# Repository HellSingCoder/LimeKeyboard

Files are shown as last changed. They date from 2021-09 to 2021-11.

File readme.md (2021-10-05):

# Lime Keyboard

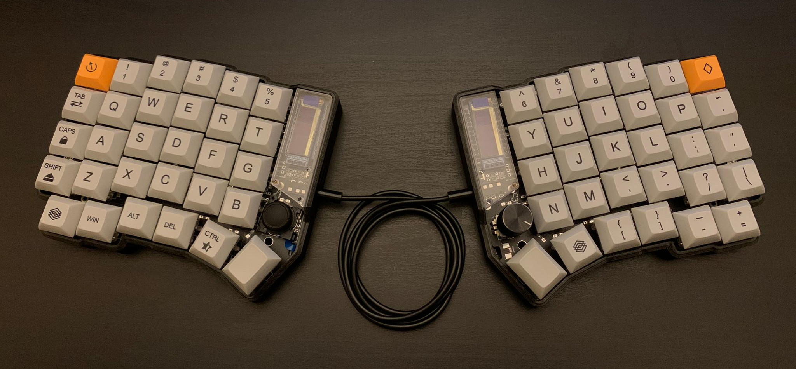
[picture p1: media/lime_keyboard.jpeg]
Lime Keyboard


Lime is a 6×4+6 keys column-staggered split keyboard with encoder and joystick support. Based on [Lily58](https://github.com/kata0510/Lily58), [Corne](https://github.com/foostan/crkbd), [Helix](https://github.com/MakotoKurauchi/helix) and [Sofle](https://github.com/josefadamcik/SofleKeyboard) keyboards. This board features a reversible PCB, OLEDs, Underglow and Bluetooth support. The PCB has holes for floating or screwed mounts but can be also mounted with a gasket.

The Lime keyboard was created by [HellTM](https://github.com/HellSingCoder) with the help of the QMK and custom keyboard community.

**If you would like one of these contact me, I will probably run a couple batches in the future.**

## Firmware 

This keyboard runs [QMK](https://qmk.fm/) (no VIA support).

## Default layout 

### Base layer
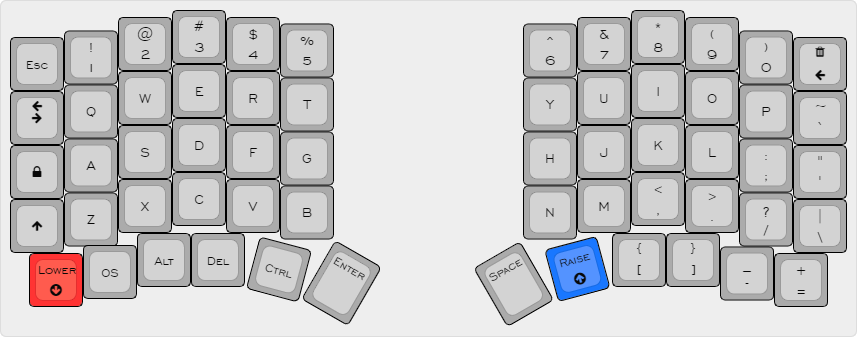
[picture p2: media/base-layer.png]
Base layout for Lime Keyboard

The layout can be switched for COLEMAK in the settings layer

### Lower layer
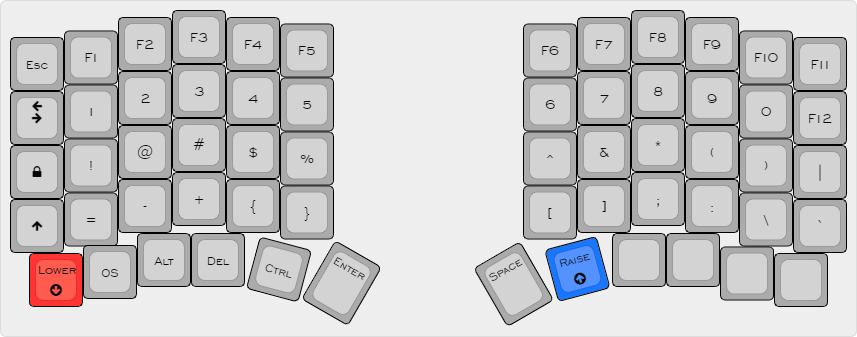
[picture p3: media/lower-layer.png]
Lower layout for Lime Keyboard


### Raise layer
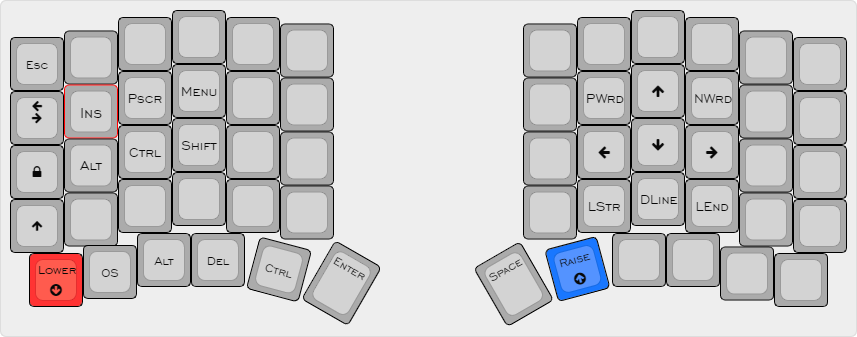
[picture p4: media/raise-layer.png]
Raise layout for Lime Keyboard


### Settings layer
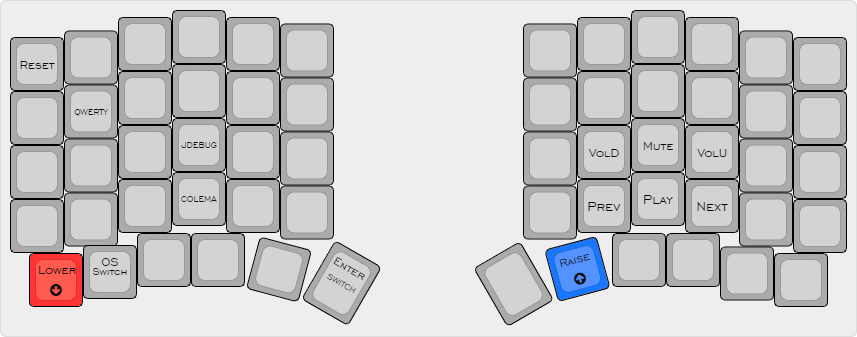
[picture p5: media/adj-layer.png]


This layer can be accessed with the following combination:

Adj layout combination for Lime Keyboard

## Extras

### Keyboard Pet (Luna)
Adj layout for Lime Keyboard

Luna jumps every time you hit Space and will bark at people on the internet if you activate Caps Lock!

This keyboard pet reacts to your WPM counter:
- under 10 -> sit
- between 10 and 50 -> walk
- over 50 -> run

### Shift + Backspace = Delete
This one is pretty self explanatory.

### Space / Enter swap
The Enter and Space functions can be swapped pressing the left thumb button from the Setting layer. The current mode will be displayed on the left display. This one may be useful to all the gamers out there!

### OS Switch
Pressing the OS button while on the settings layer will toggle the MAC / WIN mode. This corrects the behaviour of the Alt and Control modifiers. The current selection will be displayed with an icon at the top of the left display.

### Media Buttons
The right encoder controls the volume and can be pressed to mute. Extra media buttons are hidden away on the settings layer.

### RGB Underglow Support
The board features a 5 LEDs extensible or overridable underglow. Unfortunately, the default keymap does not take advantage of that because of the very limited space but, the option is out there if you want to play around with it.

### WPM indicator
Current WPM will be displayed at the bottom of the right screen.

### Joystick Debug
The JDebug button on the settings layer toggles the ADC readings of the joystick pins for X and Y axis. These will be displayed on the left OLED.

## Special thanks

[Envious](https://github.com/Envious-Data) - Kicad sage

[Dasky](https://github.com/daskygit) - Joystick Troubleshooting guru

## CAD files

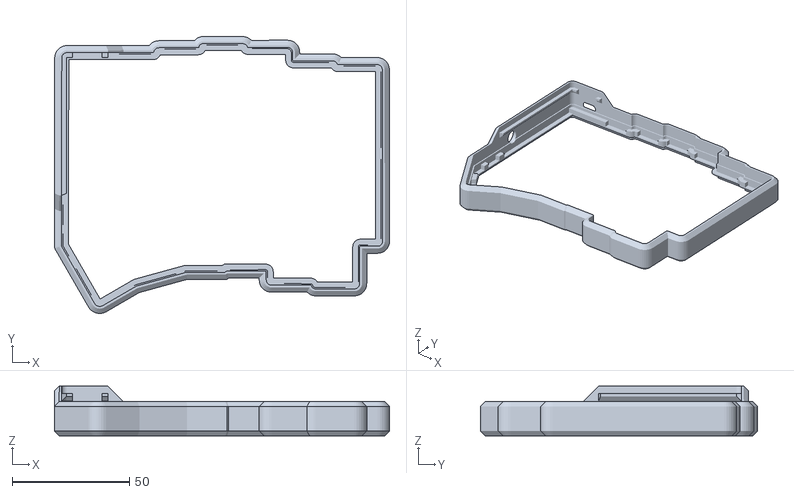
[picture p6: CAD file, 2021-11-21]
case/bumper R.stl
142.6 x 117.9 x 21.1

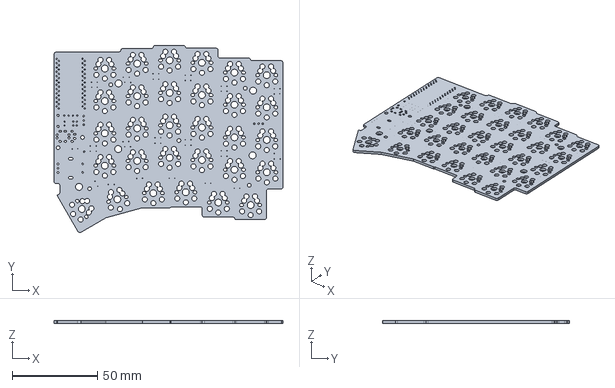
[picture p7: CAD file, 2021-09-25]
kicad/LimeKeyboard.step
134.6 x 109.9 x 1.60 mm

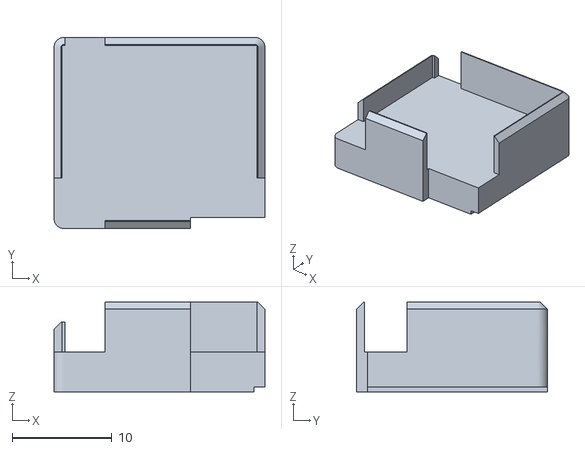
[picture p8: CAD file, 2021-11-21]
case/joystick holder.stl
21.2 x 19.2 x 9.00

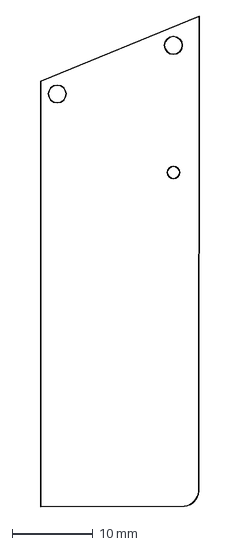
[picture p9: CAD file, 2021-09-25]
case/acrylic_screen.dxf
19.6 x 60.6 mm

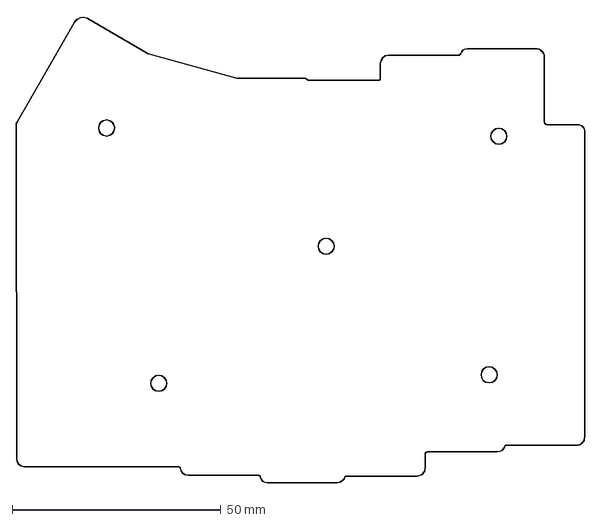
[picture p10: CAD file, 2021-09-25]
case/acrylic_bottom.dxf
136.0 x 111.6 mm

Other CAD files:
case/bumper L.stl
case/LimeKeyboard_pcb.stl

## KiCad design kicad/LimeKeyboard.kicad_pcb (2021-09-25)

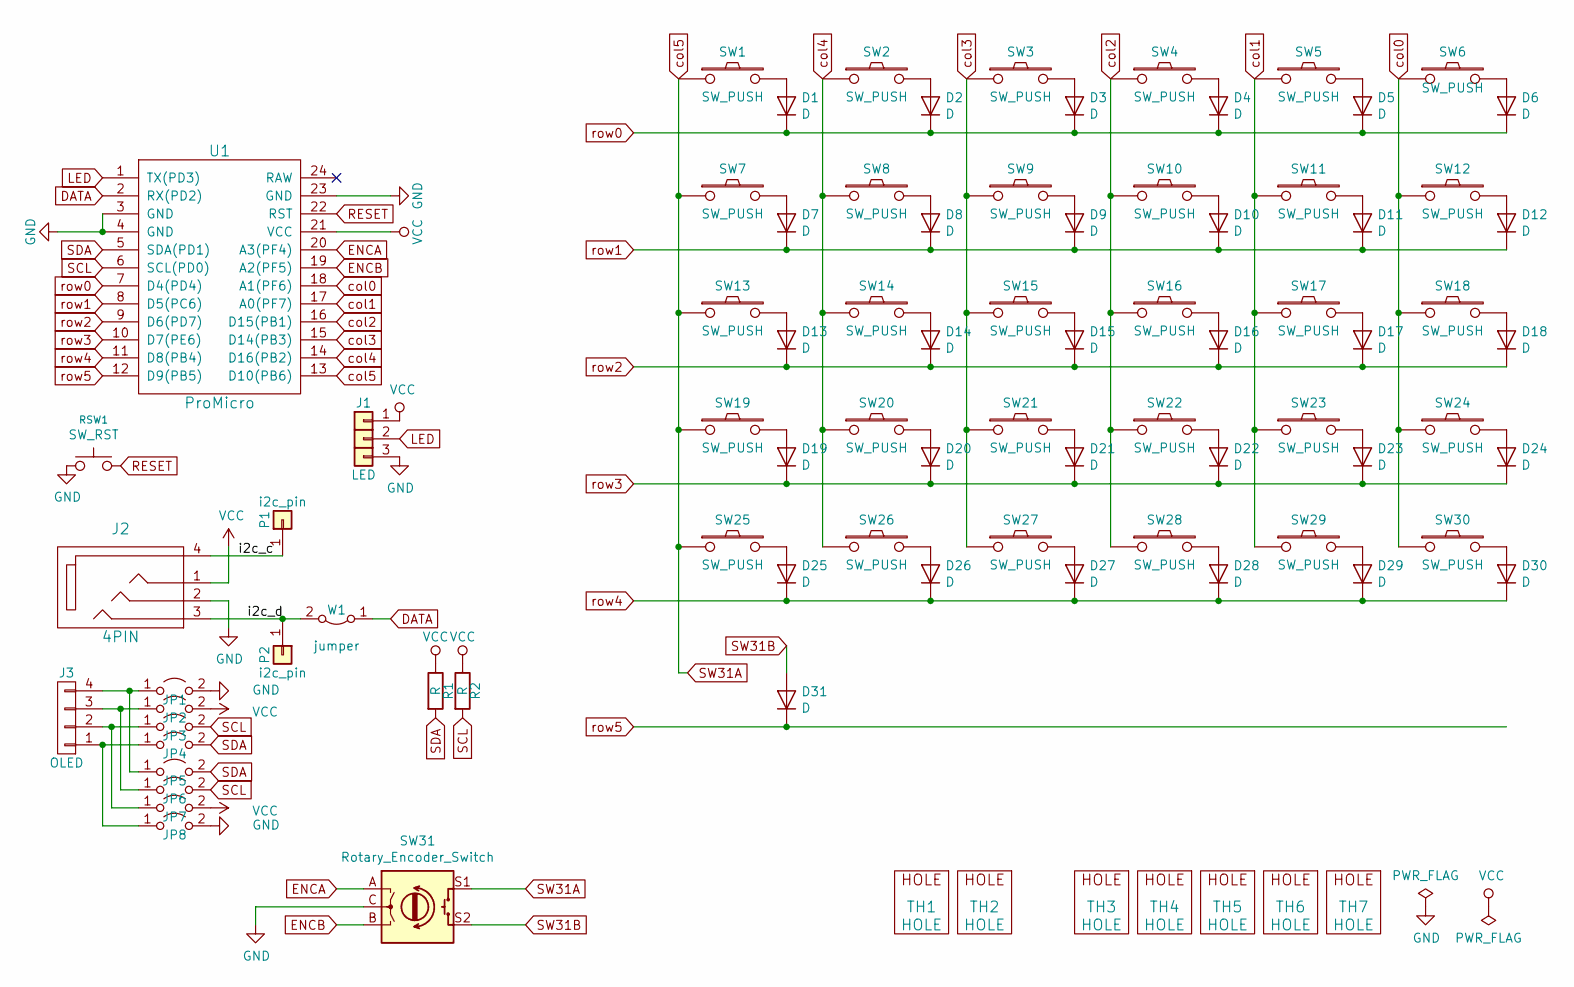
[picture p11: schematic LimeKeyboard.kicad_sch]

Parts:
D1, D2, D3, D4, D5, D6, D7, D8, D9, D10, D11, D12, D13, D14, D15, D16, D17, D18, D19, D20, D21, D22, D23, D24, D25, D26, D27, D28, D29, D30, D31: D; Diode_SOD123
J1: LED
J2: 4PIN; MJ-4PP-9
J3: OLED; OLED_4Pin
JP1, JP2, JP3, JP4, JP5, JP6, JP7, JP8: Jumper_NO_Small; Jumper
P1, P2: i2c_pin; 1pin_conn
R1, R2: R; RESISTOR_mini
RSW1: SW_RST; TACT_SWITCH_TVBP06
SW1, SW2, SW3, SW4, SW5, SW6, SW7, SW8, SW9, SW10, SW11, SW12, SW13, SW14, SW15, SW16, SW17, SW18, SW19, SW20, SW21, SW22, SW23, SW24, SW27, SW28, SW29, SW30: SW_PUSH; CherryMX_KailhLowProfile_Hotswap
SW25, SW26: SW_PUSH; CherryMX_KailhLowProfile_Hotswap_1.5
SW31: Rotary_Encoder_Switch; RotaryEncoder_Alps_EC11E-Switch_Vertical_H20mm-keebio_modif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
TH1, TH2: HOLE; M2_HOLE_PCB
TH3, TH4, TH5, TH6, TH7: HOLE; HOLE_M2_TH
U1: ProMicro
W1: jumper; jumper_data

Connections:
/i2c_c: J2.4, P1.1
/i2c_d: J2.3, P2.1, W1.2 (B)
DATA: U1.2 (RX(PD2)), W1.1 (A)
ENCA: SW31.A, U1.20 (A3(PF4))
ENCB: SW31.B, U1.19 (A2(PF5))
GND: J1.3, J2.2, JP1.2 (B), JP8.2 (B), RSW1.1, SW31.C, U1.3 (GND), U1.4 (GND), U1.23 (GND)
LED: J1.2, U1.1 (TX(PD3))
unnamed: D1.2 (A), SW1.2
unnamed: D2.2 (A), SW2.2
unnamed: D3.2 (A), SW3.2
unnamed: D4.2 (A), SW4.2
unnamed: D5.2 (A), SW5.2
unnamed: D6.2 (A), SW6.2
unnamed: D7.2 (A), SW7.2
unnamed: D8.2 (A), SW8.2
unnamed: D9.2 (A), SW9.2
unnamed: D10.2 (A), SW10.2
unnamed: D11.2 (A), SW11.2
unnamed: D12.2 (A), SW12.2
unnamed: D13.2 (A), SW13.2
unnamed: D14.2 (A), SW14.2
unnamed: D15.2 (A), SW15.2
unnamed: D16.2 (A), SW16.2
unnamed: D17.2 (A), SW17.2
unnamed: D18.2 (A), SW18.2
unnamed: D19.2 (A), SW19.2
unnamed: D20.2 (A), SW20.2
unnamed: D21.2 (A), SW21.2
unnamed: D22.2 (A), SW22.2
unnamed: D23.2 (A), SW23.2
unnamed: D24.2 (A), SW24.2
unnamed: D25.2 (A), SW25.2
unnamed: D26.2 (A), SW26.2
unnamed: D27.2 (A), SW27.2
unnamed: D28.2 (A), SW28.2
unnamed: D29.2 (A), SW29.2
unnamed: D30.2 (A), SW30.2
unnamed: J3.1, JP4.1 (A), JP8.1 (A)
unnamed: J3.2, JP3.1 (A), JP7.1 (A)
unnamed 39: J3.3, JP2.1 (A), JP6.1 (A); also elsewhere on the board
unnamed: J3.4, JP1.1 (A), JP5.1 (A)
RESET: RSW1.2, U1.22 (RST)
SCL: JP3.2 (B), JP6.2 (B), R2.2, U1.6 (SCL(PD0)); also elsewhere on the board
SDA: JP4.2 (B), JP5.2 (B), R1.2, U1.5 (SDA(PD1))
SW31A: SW1.1, SW7.1, SW13.1, SW19.1, SW25.1, SW31.S1, U1.13 (D10(PB6))
SW31B: D31.2 (A), SW31.S2
VCC: J1.1, J2.1, JP2.2 (B), JP7.2 (B), R1.1, R2.1, U1.21 (VCC)
col0: SW6.1, SW12.1, SW18.1, SW24.1, SW30.1, U1.18 (A1(PF6))
col1: SW5.1, SW11.1, SW17.1, SW23.1, SW29.1, U1.17 (A0(PF7))
col2: SW4.1, SW10.1, SW16.1, SW22.1, SW28.1, U1.16 (D15(PB1))
col3: SW3.1, SW9.1, SW15.1, SW21.1, SW27.1, U1.15 (D14(PB3))
col4: SW2.1, SW8.1, SW14.1, SW20.1, SW26.1, U1.14 (D16(PB2))
row0: D1.1 (K), D2.1 (K), D3.1 (K), D4.1 (K), D5.1 (K), D6.1 (K), U1.7 (D4(PD4))
row1: D7.1 (K), D8.1 (K), D9.1 (K), D10.1 (K), D11.1 (K), D12.1 (K), U1.8 (D5(PC6))
row2: D13.1 (K), D14.1 (K), D15.1 (K), D16.1 (K), D17.1 (K), D18.1 (K), U1.9 (D6(PD7))
row3: D19.1 (K), D20.1 (K), D21.1 (K), D22.1 (K), D23.1 (K), D24.1 (K), U1.10 (D7(PE6))
row4: D25.1 (K), D26.1 (K), D27.1 (K), D28.1 (K), D29.1 (K), D30.1 (K), U1.11 (D8(PB4))
row5: D31.1 (K), U1.12 (D9(PB5))

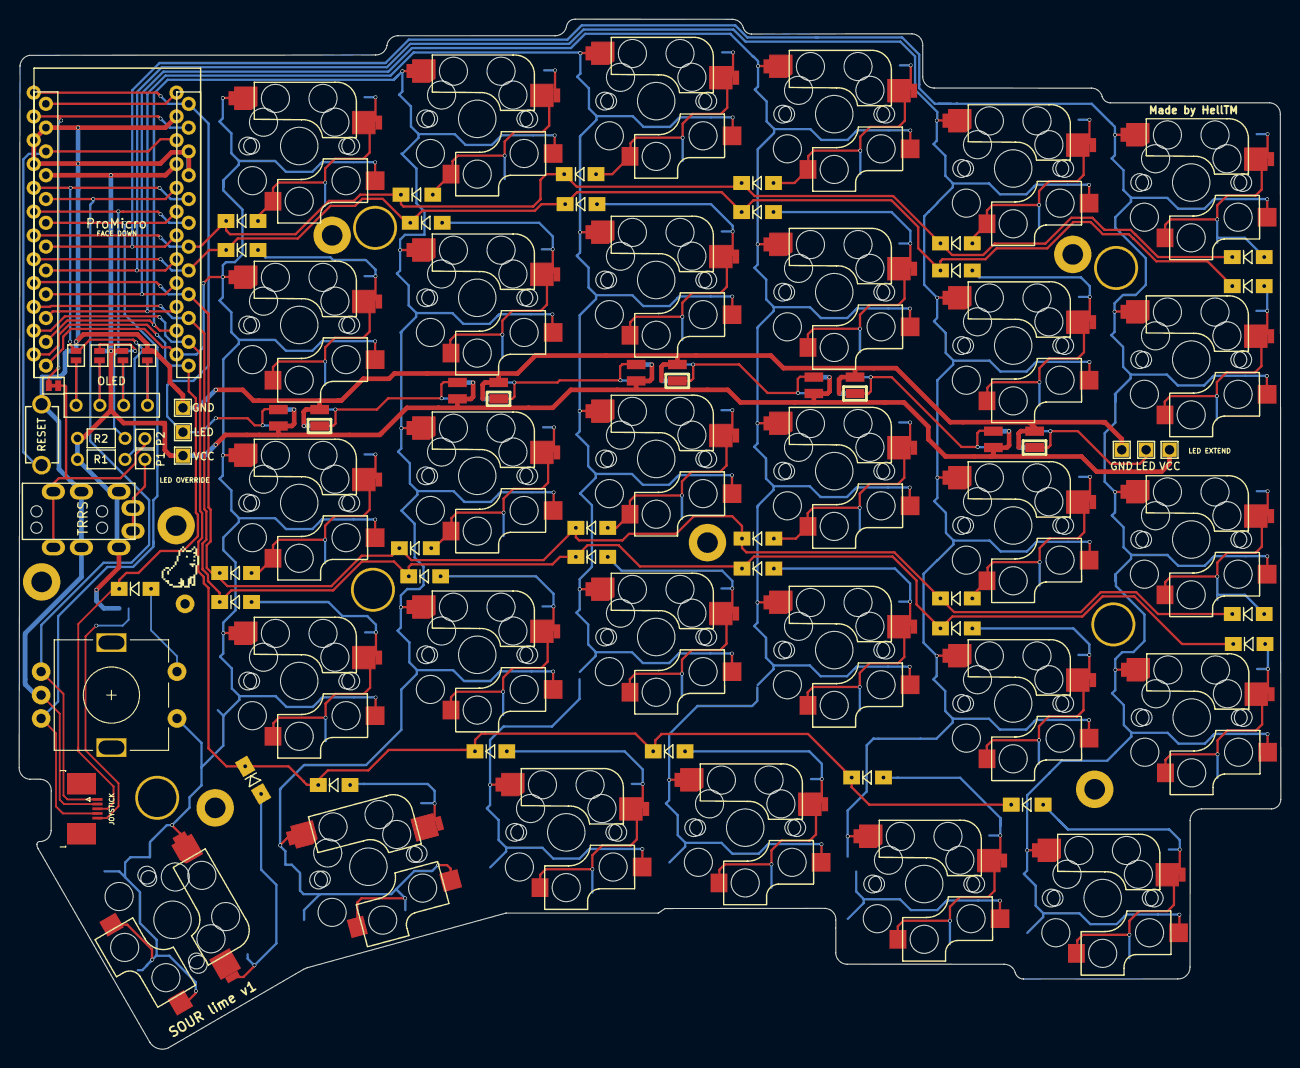
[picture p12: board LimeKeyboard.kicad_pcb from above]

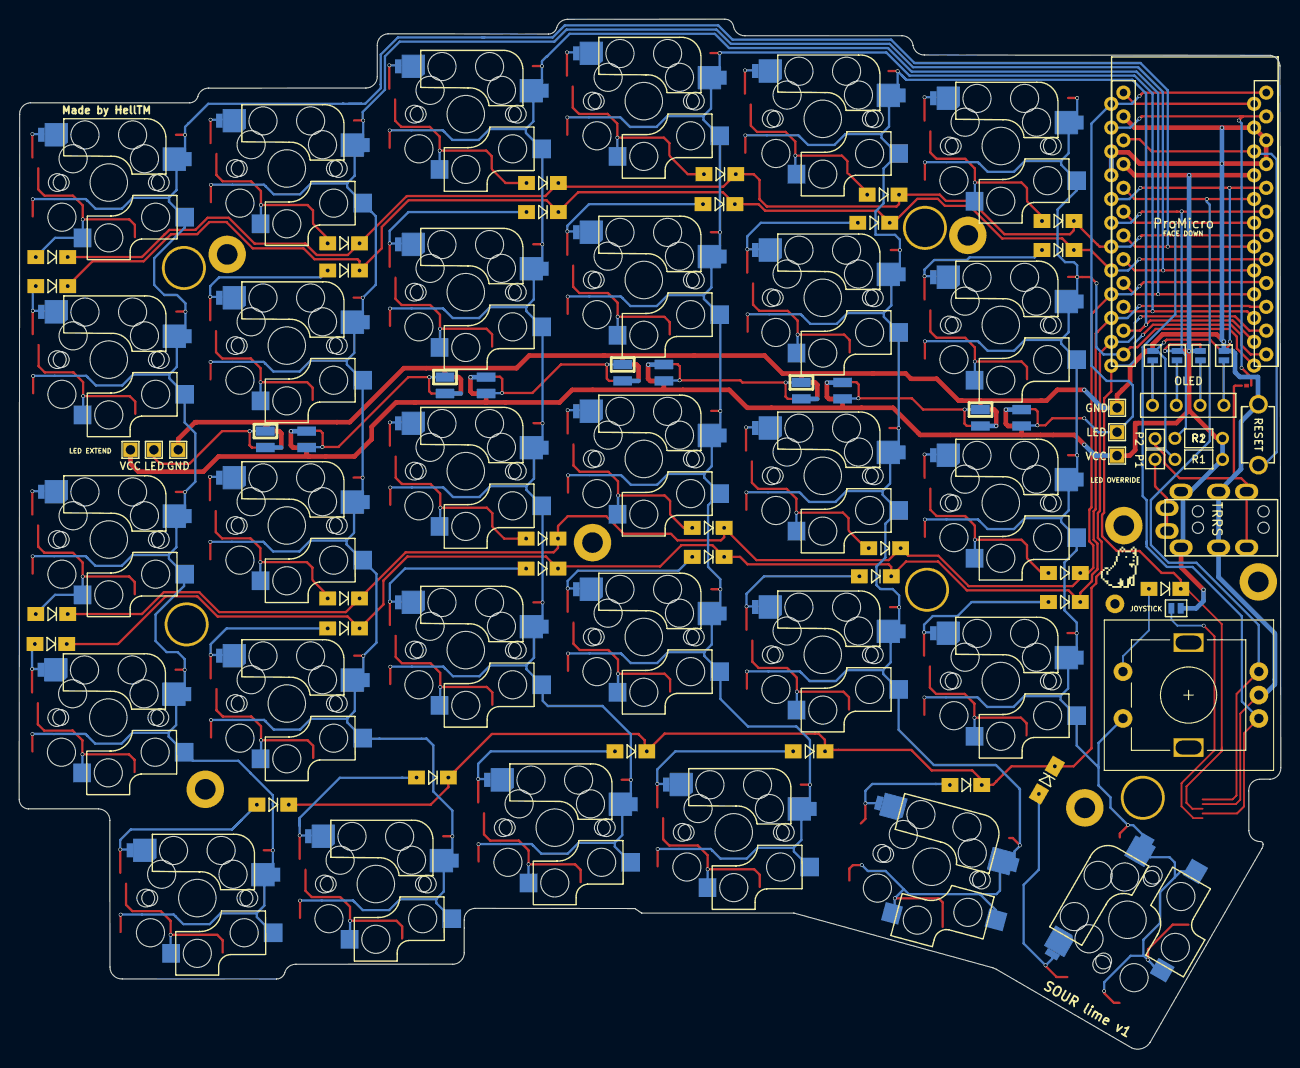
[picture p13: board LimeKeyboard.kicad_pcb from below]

Board: 2 copper layers, 134.6 x 109.9 mm, 102 parts (6 on the bottom side), 57 nets.

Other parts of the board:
D32, D33, D34, D35, D36: LED_sk2812_SM; SK6812MINI_underglow_dev
JOYSTICK: PCB Edge; TE_0-1734839-5_1x05-1MP_P0.5mm_Horizontal
JP6#2: Jumper_NO_Small; Jumper
LED: LED
LED#2: LED
LOGO: Luna
LOGO#2: Luna
TH3#2, TH4#2, TH6#2, TH7#2: HOLE; HOLE_M2_TH
TH5#2: HOLE; M2_HOLE_PCB

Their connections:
unnamed 39: JP6#2.1 (A); also elsewhere on the board
SCL: JP6#2.2 (B); also elsewhere on the board

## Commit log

2021-08-06 slim case
    [acrylic bottom.stl, bumper L.stl, bumper R.stl]
2021-09-25 new version
    [LimeKeyboard-B_Adhesive.gbr, LimeKeyboard-B_Cu.gbr, LimeKeyboard-B_Mask.gbr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]
2021-09-25 added pcb stl
    [LimeKeyboard_pcb.stl]
2021-09-25 made sure things are all local to this project
    [LimeKeyboard.kicad_pcb, LimeKeyboard.kicad_sch]
2021-10-05 folders cleanup
    [LimeKeyboard.kicad_pcb, LimeKeyboard.kicad_sch, LimeKeyboard.step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]
2021-11-21 new case files
    [bumper L.stl, bumper R.stl, joystick holder.stl]
